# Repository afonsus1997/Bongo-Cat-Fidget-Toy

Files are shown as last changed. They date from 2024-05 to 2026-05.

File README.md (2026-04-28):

# Bongo Cat Fidget Toy

<p align="center">
  Demo 1
  Demo 2
</p>







A simple and satisfying electronic fidget toy featuring Bongo Cat. Track your taps, measure your speed, and toggle display options with intuitive controls.

> 

> **Now available on [Tindie](https://www.tindie.com/products/afonsus1997/bongo-cat-fidget-toy/)!**

---

## Features

* Tap counter with automatic saving to persistent memory  
* Tap speed measurement  
* Milestones
* Sleep animation
* Optional overlay display  

---

## Instructions

### Power

- Requires a single CR2032 battery (positive side up)

### In-Use Controls

* **Hold both buttons** to enable or disable the overlay
  
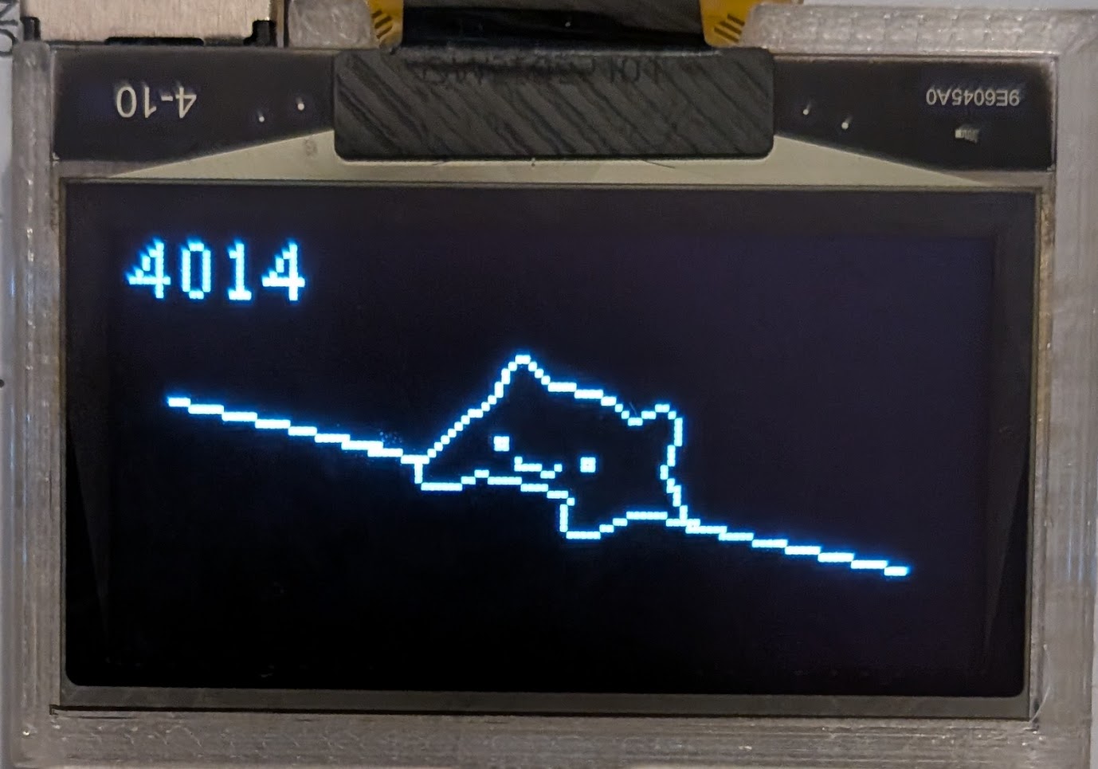
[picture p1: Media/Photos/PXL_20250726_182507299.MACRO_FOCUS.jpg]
  

### Power-On Modes

* **Hold the right button while powering on** to enter reset mode
  
  An additional press is required to confirm
  
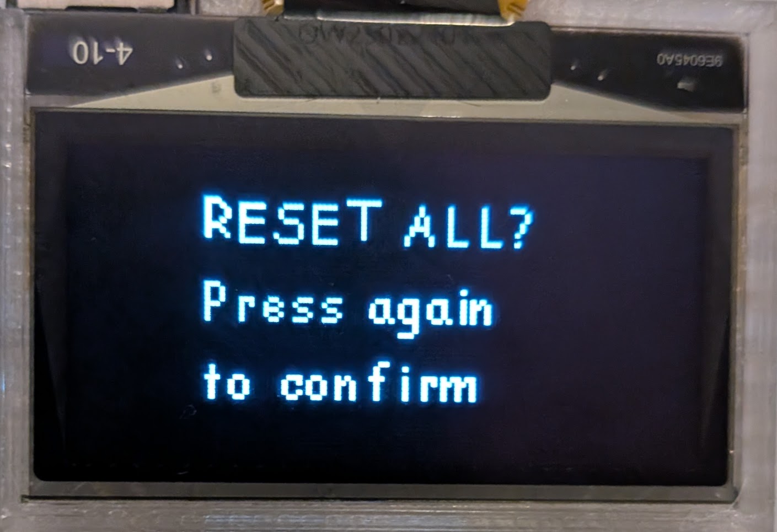
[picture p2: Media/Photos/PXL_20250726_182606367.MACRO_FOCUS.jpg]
  

* **Hold both buttons while powering on** to display the credits
  
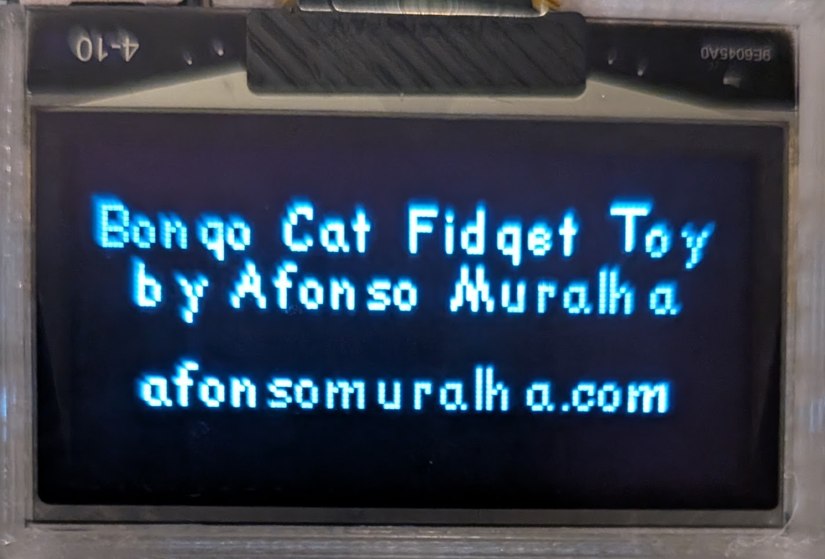
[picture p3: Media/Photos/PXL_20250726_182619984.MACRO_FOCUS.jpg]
  

---

## Gallery

|  |  |
| --- | --- |
|  |  |
|  |  |

---

## Credits

* Switch models by [koktoh](https://github.com/koktoh/keyswitch_model)

---

## AI Disclaimer

All hardware design, firmware, and software in this project were developed by hand. No AI tools were used for circuit design, PCB layout, firmware architecture, code logic, or image/asset generation. AI assistance was limited to aiding software development debugging and porting efforts.

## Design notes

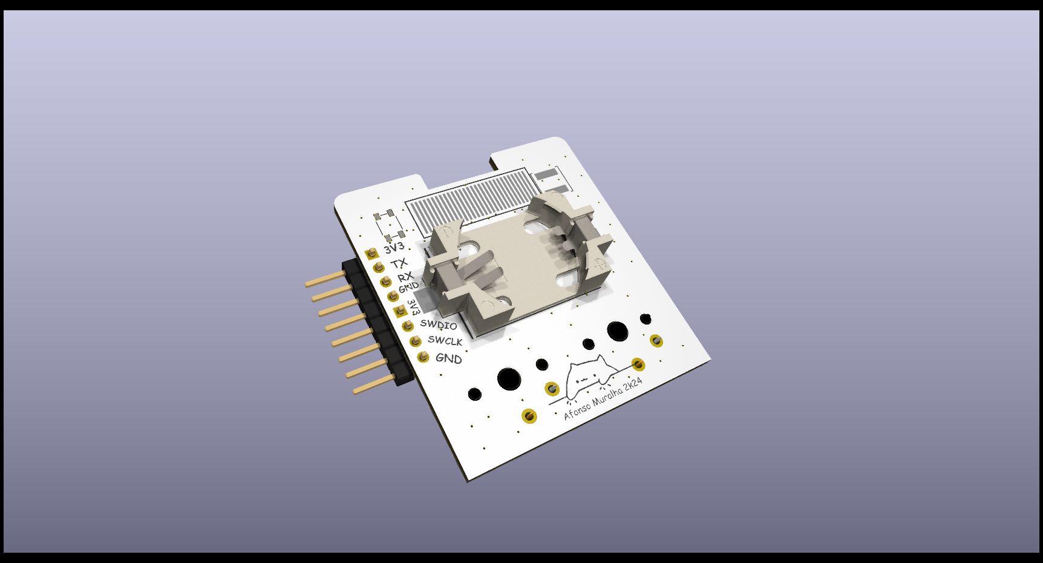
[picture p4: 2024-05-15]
Hardware/Bongo-Cat-Fidget-Toy-Lite/Bongo-Cat-Fidget-Toy-Lite/media/render_bot.png

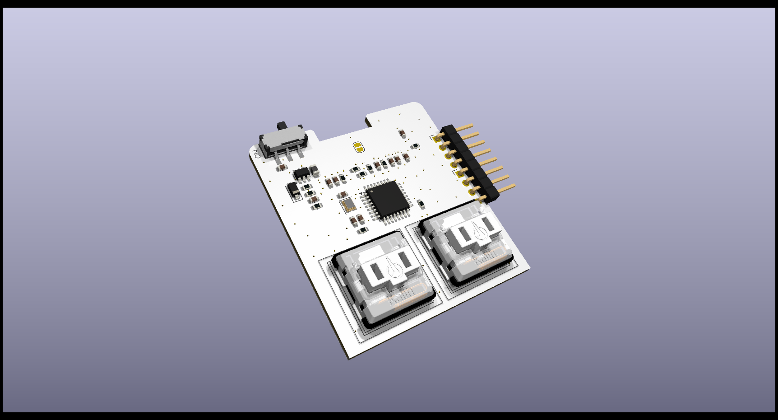
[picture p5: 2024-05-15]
Hardware/Bongo-Cat-Fidget-Toy-Lite/Bongo-Cat-Fidget-Toy-Lite/media/render_top.png

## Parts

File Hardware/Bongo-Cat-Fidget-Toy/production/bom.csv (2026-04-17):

Designator | Footprint | Quantity | Value | LCSC Part #
BT1 | BAT-TH_CR2032-BS-6-1 | 1 | Battery | C70377
C1, C2 | 603 | 2 | 22uF | C59461
C10, C11, C13, C8, C9 | 603 | 5 | 2.2uF | C23630
C12, C4 | 603 | 2 | 4.7uF | C1705
C3, C5 | 603 | 2 | 100nF | C30926
L102 | L_Wurth_WE-LQSH-2010 | 1 | 0.47uH | C89446
R1, R101, R2, R4, R8 | 603 | 5 | 91k | C326721
R11 | 603 | 1 | 390k | C23150
R12, R13 | 603 | 2 | 4.7k | C23162
R6 | 603 | 1 | 511k | C2684557
SW5 | SW-SMD_SK-3245S-L1-A-1 | 1 | SW_SPDT_321 | C405951
U1 | LQFP-32_7x7mm_P0.8mm | 1 | STM32G030K8Tx | C724044
U101 | VREG_TPS63802DLAR | 1 | TPS63802DLAR | C2845237

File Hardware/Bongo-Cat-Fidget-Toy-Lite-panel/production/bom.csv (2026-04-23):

Designator | Footprint | Quantity | Value | LCSC Part #
BT1_12, BT1_11, BT1_10, BT1_9, BT1_8, BT1_7, BT1_6, BT1_5, BT1_4, BT1_3, BT1_2, BT1 | BAT-TH_CR2032-BS-6-1 | 12 | Battery | C70377
C1_12, C1_11, C1_10, C1_9, C1_8, C1_7, C1_6, C1_5, C1_4, C1_3, C1_2, C1, C2_12, C2_11, C2_10, C2_9, C2_8, C2_7, C2_6, C2_5, C2_4, C2_3, C2_2, C2 | 0603 | 24 | 22uF | C59461
C10_12, C10_11, C10_10, C10_9, C10_8, C10_7, C10_6, C10_5, C10_4, C10_3, C10_2, C10, C11_12, C11_11, C11_10, C11_9, C11_8, C11_7, C11_6, C11_5, C11_4, C11_3, C11_2, C11, C13_12, C13_11, C13_10, C13_9, C13_8, C13_7, C13_6, C13_5, C13_4, C13_3, C13_2, C13, C8_12, C8_11, C8_10, C8_9, C8_8, C8_7, C8_6, C8_5, C8_4, C8_3, C8_2, C8, C9_12, C9_11, C9_10, C9_9, C9_8, C9_7, C9_6, C9_5, C9_4, C9_3, C9_2, C9 | 0603 | 60 | 2.2uF
C12_12, C12_11, C12_10, C12_9, C12_8, C12_7, C12_6, C12_5, C12_4, C12_3, C12_2, C12, C4_12, C4_11, C4_10, C4_9, C4_8, C4_7, C4_6, C4_5, C4_4, C4_3, C4_2, C4 | 0603 | 24 | 4.7uF | C1705
C3_12, C3_11, C3_10, C3_9, C3_8, C3_7, C3_6, C3_5, C3_4, C3_3, C3_2, C3 | 0603 | 12 | 100nF
L102_12, L102_11, L102_10, L102_9, L102_8, L102_7, L102_6, L102_5, L102_4, L102_3, L102_2, L102 | L_Wurth_WE-LQSH-2010 | 12 | 0.47uH | C89446
R101_12, R101_11, R101_10, R101_9, R101_8, R101_7, R101_6, R101_5, R101_4, R101_3, R101_2, R101, R4_12, R4_11, R4_10, R4_9, R4_8, R4_7, R4_6, R4_5, R4_4, R4_3, R4_2, R4 | 0603 | 24 | 91k
R11_12, R11_11, R11_10, R11_9, R11_8, R11_7, R11_6, R11_5, R11_4, R11_3, R11_2, R11 | 0603 | 12 | 390k
R12_12, R12_11, R12_10, R12_9, R12_8, R12_7, R12_6, R12_5, R12_4, R12_3, R12_2, R12, R13_12, R13_11, R13_10, R13_9, R13_8, R13_7, R13_6, R13_5, R13_4, R13_3, R13_2, R13 | 0603 | 24 | 4.7k
R6_12, R6_11, R6_10, R6_9, R6_8, R6_7, R6_6, R6_5, R6_4, R6_3, R6_2, R6 | 0603 | 12 | 511k
SW5_12, SW5_11, SW5_10, SW5_9, SW5_8, SW5_7, SW5_6, SW5_5, SW5_4, SW5_3, SW5_2, SW5 | SW-SMD_SK-3245S-L1-A-1 | 12 | SW_SPDT_321 | C405951
U101_12, U101_11, U101_10, U101_9, U101_8, U101_7, U101_6, U101_5, U101_4, U101_3, U101_2, U101 | VREG_TPS63802DLAR | 12 | TPS63802DLAR | C2845237
U2_12, U2_11, U2_10, U2_9, U2_8, U2_7, U2_6, U2_5, U2_4, U2_3, U2_2, U2 | QFN-20-1EP_3x3mm_P0.4mm_EP1.65x1.65mm | 12 | PY32F003F1xU | C3018714

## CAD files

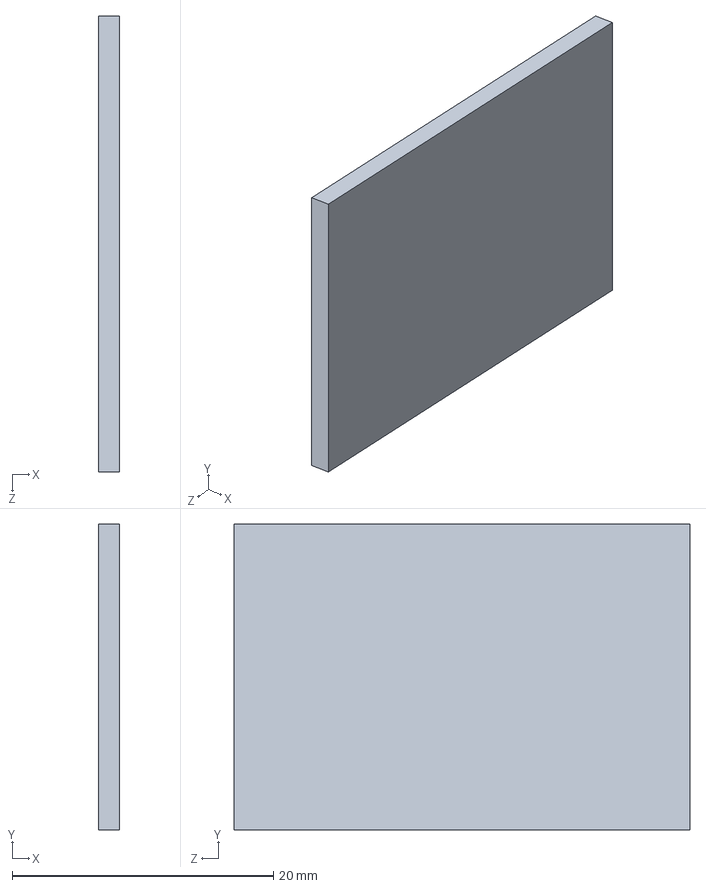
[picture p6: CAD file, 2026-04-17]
Hardware/3D/LCD.SLDPRT
1.60 x 23.4 x 34.9 mm

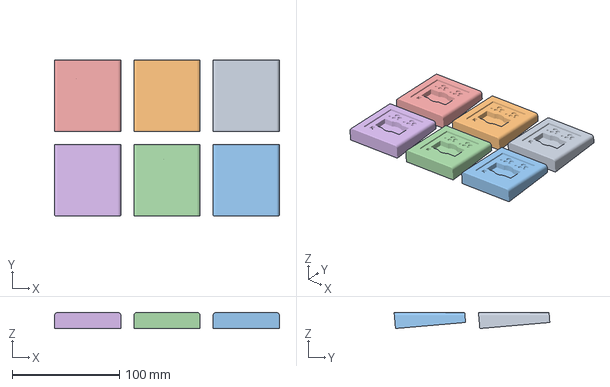
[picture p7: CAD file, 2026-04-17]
Hardware/Bongo-Cat-Fidget-Toy-Lite/Bongo-Cat-Fidget-Toy-Lite/box_insert_bambulab.3mf
210.0 x 145.4 x 15.0 mm
box_insert.stl x 6

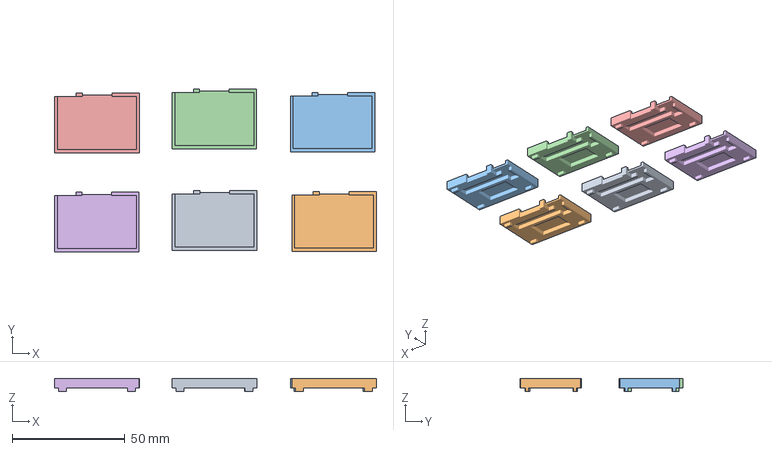
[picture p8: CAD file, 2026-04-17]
Hardware/Bongo-Cat-Fidget-Toy/LCD_support_bambulab_new.3mf
142.5 x 72.2 x 5.95 mm
LCD Support - LCD Support-1.STL x 6

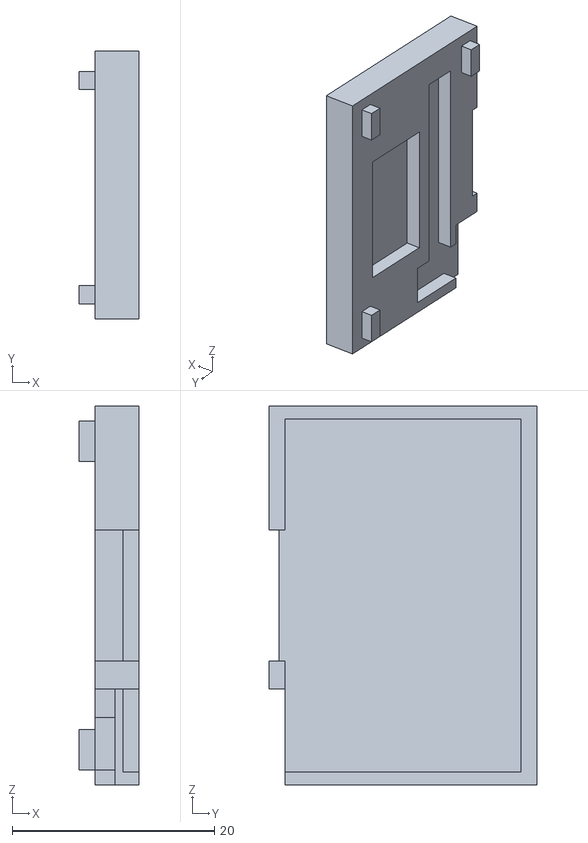
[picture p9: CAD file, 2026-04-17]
Hardware/3D/LCD Support_0.0.STL
5.95 x 26.5 x 37.5

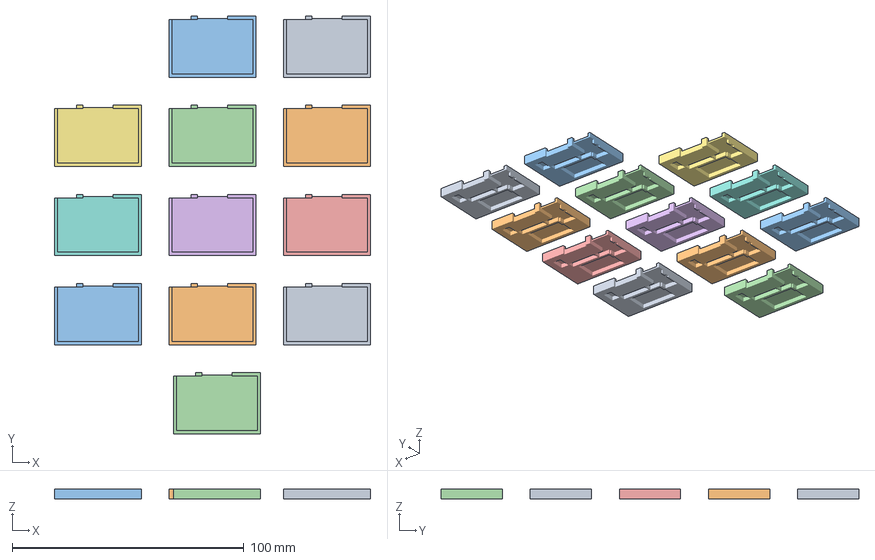
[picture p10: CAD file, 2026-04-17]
Hardware/Bongo-Cat-Fidget-Toy-Lite/Bongo-Cat-Fidget-Toy-Lite/LCD_support_bambulab.3mf
136.5 x 180.5 x 4.35 mm
LCD support.stl x 12

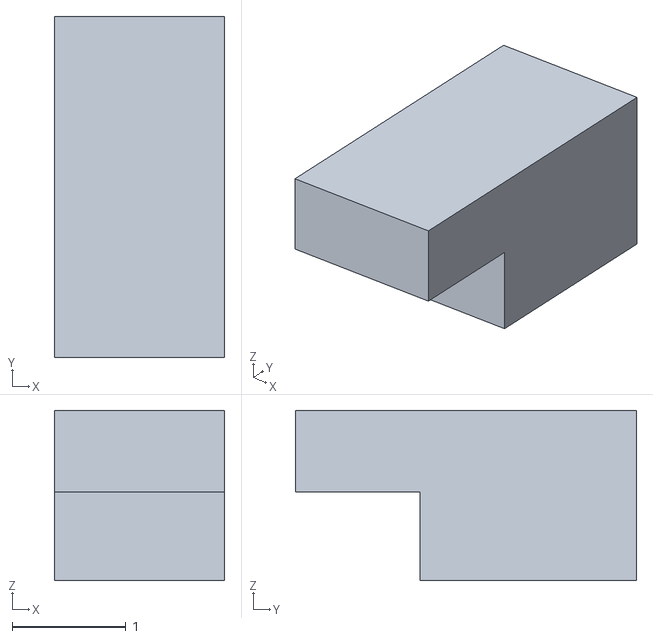
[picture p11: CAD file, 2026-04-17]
Hardware/3D/LCD Support - Bongo-Cat-Fidget-Toy.step-1 SW-SMD_SK-3245S-L1-A-1.step-1 SOLID-1.step-1.STL
1.50 x 3.00 x 1.50

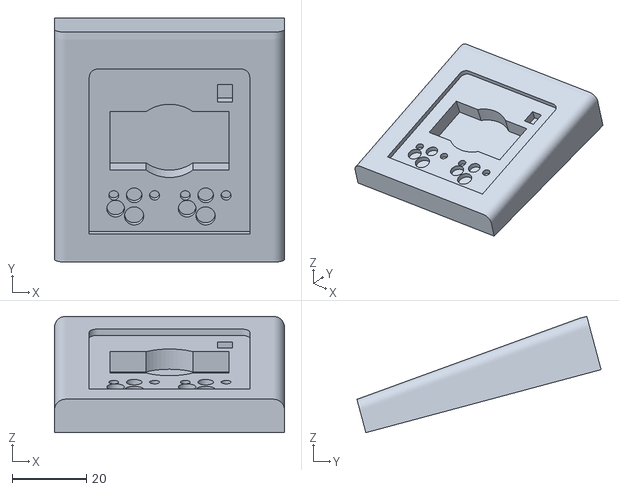
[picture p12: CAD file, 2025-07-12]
Hardware/Bongo-Cat-Fidget-Toy-Lite/Bongo-Cat-Fidget-Toy-Lite/box_insert.stl
62.0 x 65.8 x 31.4

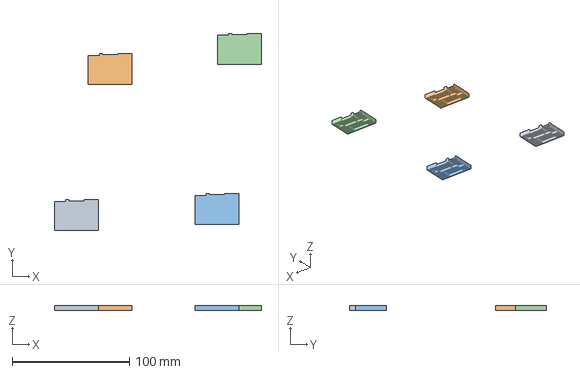
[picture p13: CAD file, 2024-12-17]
Hardware/Bongo-Cat-Fidget-Toy/LCD_support_bambulab.3mf
176.7 x 168.4 x 4.35 mm
LCD support.stl x 4

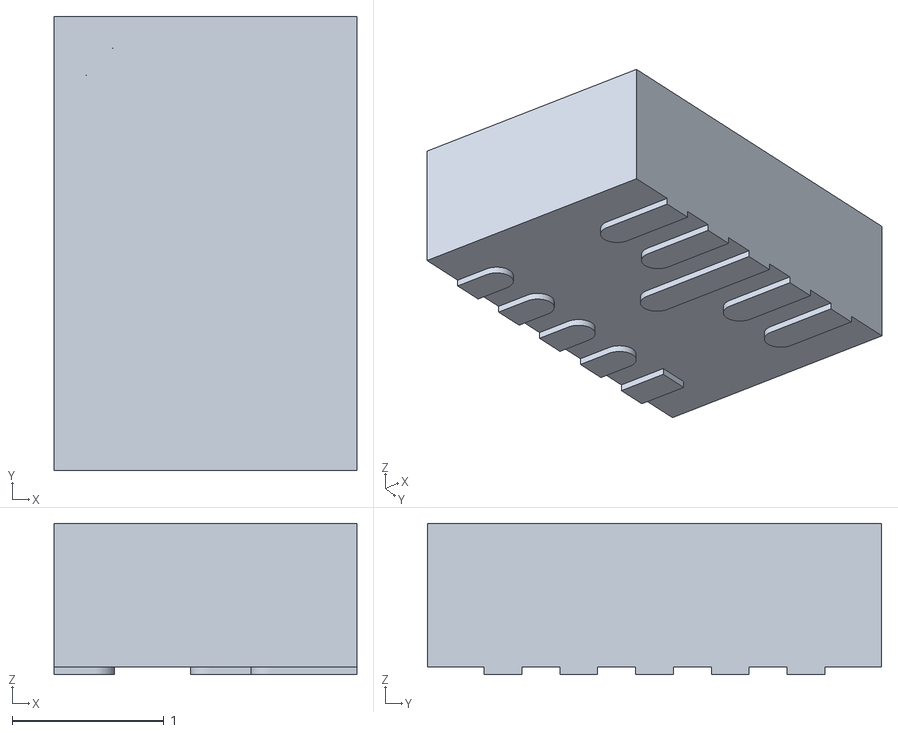
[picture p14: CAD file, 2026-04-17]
Hardware/3D/LCD Support - Bongo-Cat-Fidget-Toy.step-1 TPS63802DLAR.step-1.STL
2.00 x 3.00 x 1.00

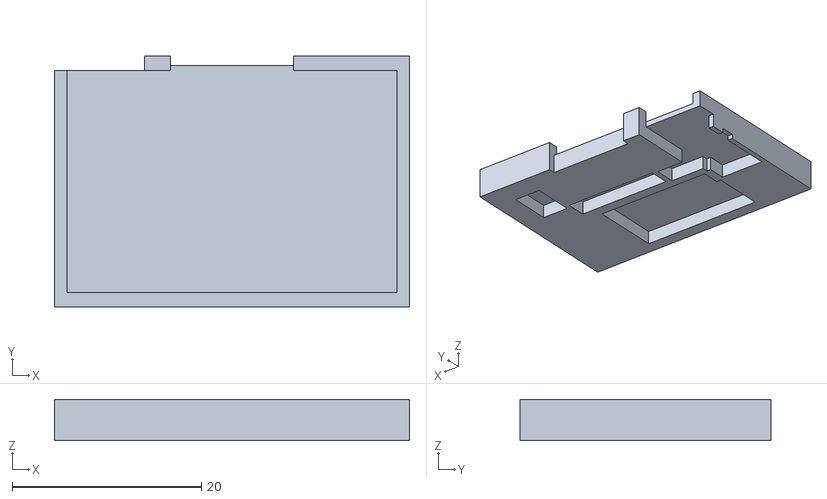
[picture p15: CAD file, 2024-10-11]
Hardware/Bongo-Cat-Fidget-Toy-Lite/Bongo-Cat-Fidget-Toy-Lite/LCD support.stl
37.5 x 26.5 x 4.35

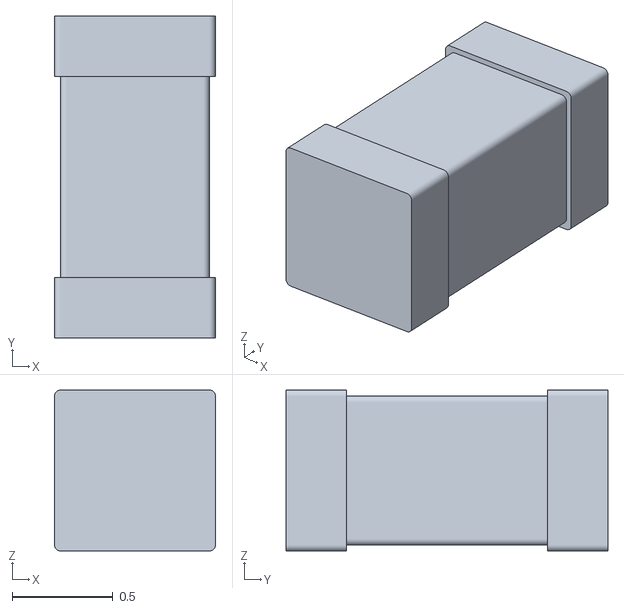
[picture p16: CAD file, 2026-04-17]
Hardware/3D/LCD Support - Bongo-Cat-Fidget-Toy.step-1 C_0603_1608Metric.step-11.STL
0.8 x 1.60 x 0.8

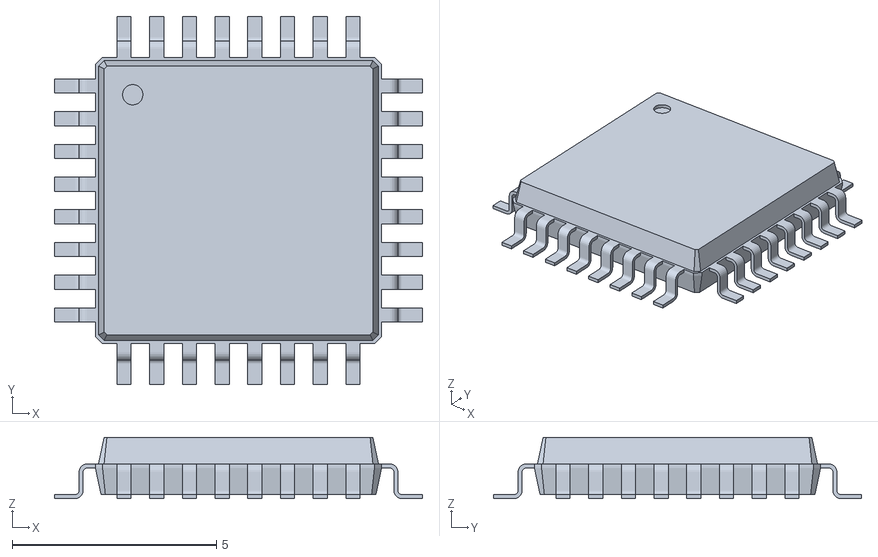
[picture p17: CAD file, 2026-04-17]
Hardware/3D/LCD Support - Bongo-Cat-Fidget-Toy.step-1 LQFP-32_7x7mm_P0.8mm.step-1.STL
9.00 x 9.00 x 1.50

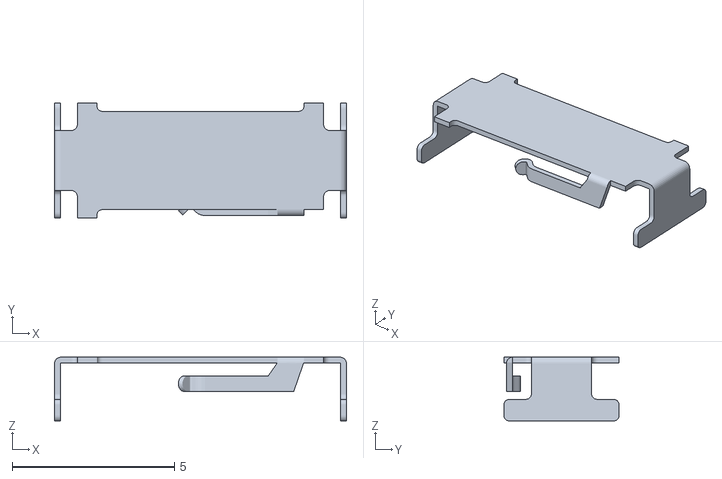
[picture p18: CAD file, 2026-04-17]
Hardware/3D/LCD Support - Bongo-Cat-Fidget-Toy.step-1 SW-SMD_SK-3245S-L1-A-1.step-1 SOLID-0.step-1.STL
9.00 x 3.55 x 1.97

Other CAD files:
Hardware/Bongo-Cat-Fidget-Toy/box_insert_bambulab.3mf
Hardware/3D/LCD Support - Bongo-Cat-Fidget-Toy.step-1 C_0603_1608Metric.step-2.STL
Hardware/3D/LCD Support - Bongo-Cat-Fidget-Toy.step-1 C_0603_1608Metric.step-5.STL
Hardware/3D/LCD Support_-0.2.STL
Hardware/3D/LCD Support_-0.1.STL
Hardware/3D/LCD Support - Bongo-Cat-Fidget-Toy.step-1 Bongo-Cat-Fidget-Toy_PCB.step-1.STL
Hardware/3D/LCD Support - Bongo-Cat-Fidget-Toy.step-1 C_0603_1608Metric.step-1.STL
Hardware/3D/LCD Support - Bongo-Cat-Fidget-Toy.step-1 C_0603_1608Metric.step-10.STL
Hardware/3D/LCD Support - Bongo-Cat-Fidget-Toy.step-1 C_0603_1608Metric.step-3.STL
Hardware/3D/LCD Support - Bongo-Cat-Fidget-Toy.step-1 C_0603_1608Metric.step-4.STL
Hardware/3D/LCD Support - Bongo-Cat-Fidget-Toy.step-1 C_0603_1608Metric.step-6.STL
Hardware/3D/LCD Support - Bongo-Cat-Fidget-Toy.step-1 C_0603_1608Metric.step-7.STL
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

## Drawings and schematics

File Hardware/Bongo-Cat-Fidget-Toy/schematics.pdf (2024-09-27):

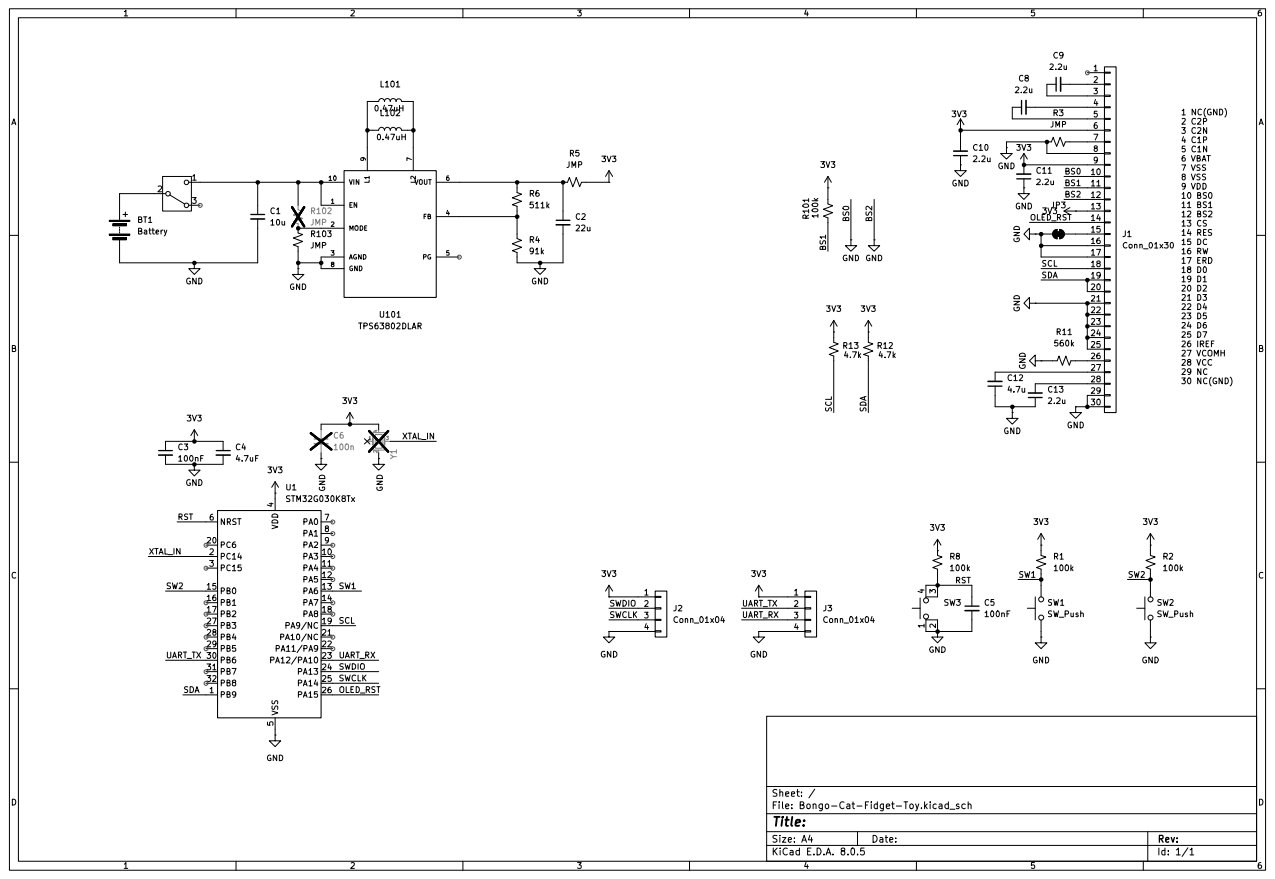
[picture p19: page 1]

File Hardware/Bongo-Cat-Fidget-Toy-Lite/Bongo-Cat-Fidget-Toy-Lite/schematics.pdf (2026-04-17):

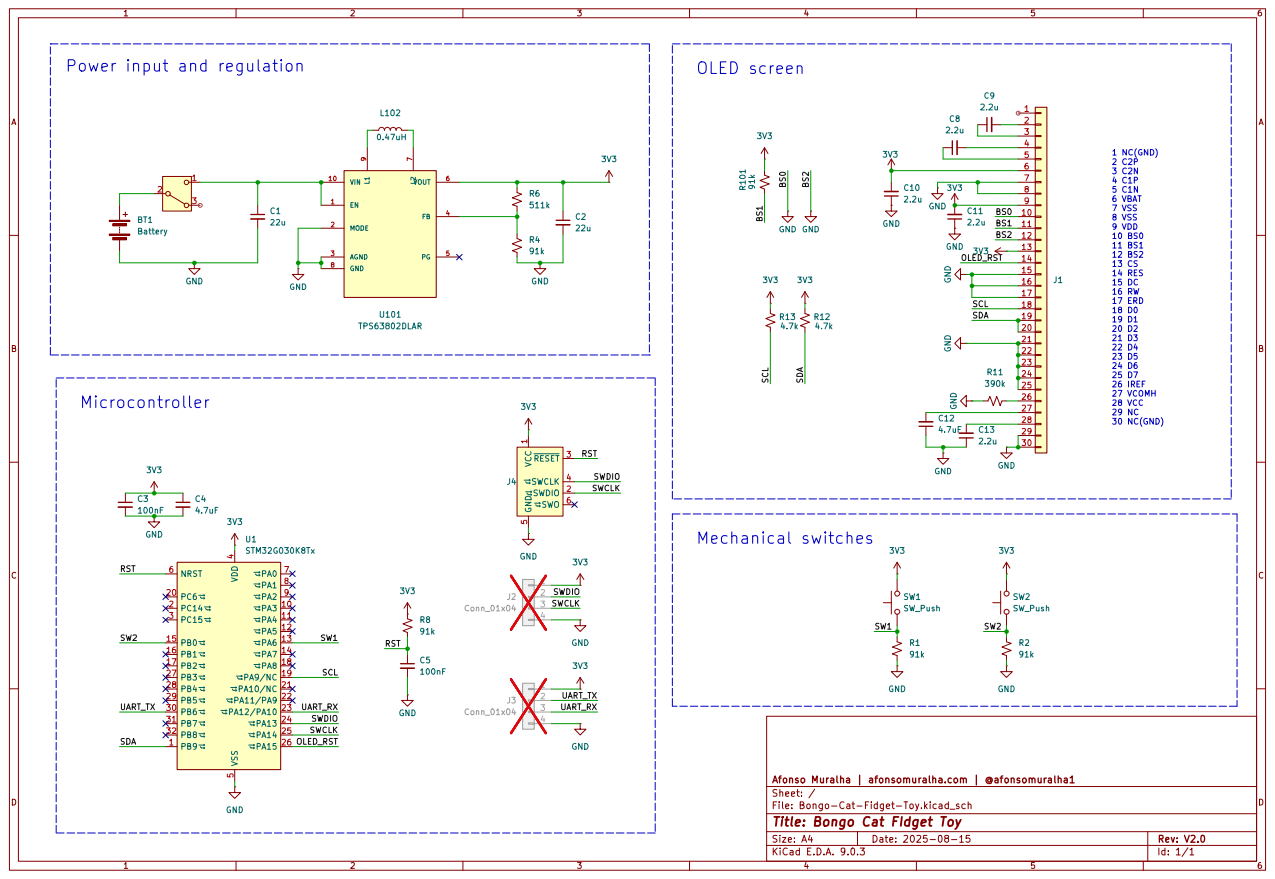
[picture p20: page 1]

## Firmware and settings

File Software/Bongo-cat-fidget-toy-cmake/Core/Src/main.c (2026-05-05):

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
/* Includes ------------------------------------------------------------------*/
#include "main.h"

/* USER CODE BEGIN Includes */
#include "ssd1306.h"
#include "buttons.h"
#include "settings.h"
#include "tap_tracker.h"
#include "animation.h"
#include "ui.h"
/* USER CODE END Includes */

/* USER CODE BEGIN PTD */
typedef enum {
    IDLE,
    SWITCH,
} state_e;
/* USER CODE END PTD */

I2C_HandleTypeDef hi2c1;
TIM_HandleTypeDef htim14;

void SystemClock_Config(void);
static void MX_GPIO_Init(void);
static void MX_I2C1_Init(void);
static void MX_TIM14_Init(void);
static void MX_NVIC_Init(void);
/* USER CODE BEGIN 0 */
void HAL_TIM_PeriodElapsedCallback(TIM_HandleTypeDef *htim)
{
    if (htim == &htim14)
    {
        readPins();
    }
}
/* USER CODE END 0 */

/**
  * @brief  The application entry point.
  * @retval int
  */
int main(void)
{
  HAL_Init();

  SystemClock_Config();

  MX_GPIO_Init();
  MX_I2C1_Init();
  MX_TIM14_Init();
  MX_NVIC_Init();

  /* USER CODE BEGIN 2 */
  HAL_GPIO_WritePin(OLED_RST_GPIO_Port, OLED_RST_Pin, GPIO_PIN_RESET);
  HAL_Delay(10);
  HAL_GPIO_WritePin(OLED_RST_GPIO_Port, OLED_RST_Pin, GPIO_PIN_SET);
  ssd1306_Init();
  ssd1306_SetContrast(DISPLAY_CONTRAST);

  tap_tracker_reset();
  last_save_time = HAL_GetTick();

  handle_boot_overrides();
  load_settings();

  state_e state       = IDLE;
  uint8_t idle_cnt    = 0;
  int32_t idle_cntr   = 0;
  int32_t tap_left_cntr  = 0;
  int32_t tap_right_cntr = 0;
  uint8_t left_state  = 0;
  uint8_t right_state = 0;

  uint32_t idle_since      = 0;
  uint32_t sleep_zzz_timer = 0;
  uint8_t  sleep_zzz_frame = 0;

  HAL_TIM_Base_Start_IT(&htim14);

  while (1) {
    check_and_save();
    update_saved_indicator();
    update_tap_speed();

    switch (state) {
    case IDLE:
        if (sw_state_left == 0 || sw_state_right == 0) {
            if (!ssd1306_GetDisplayOn()) ssd1306_SetDisplayOn(1);
            state        = SWITCH;
            idle_since   = 0;
        } else {
            if (idle_since == 0) {
                idle_since      = HAL_GetTick();
                sleep_zzz_timer = idle_since;
                sleep_zzz_frame = 0;
            }

            uint32_t elapsed = HAL_GetTick() - idle_since;

            if (elapsed >= SLEEP_DELAY + DISPLAY_OFF_DELAY) {
                if (ssd1306_GetDisplayOn()) ssd1306_SetDisplayOn(0);
            } else if (elapsed >= SLEEP_DELAY) {
                draw_sleep_frame();
                draw_zzz_overlay(sleep_zzz_frame);
                update_display_with_overlays();
                if (HAL_GetTick() - sleep_zzz_timer >= SLEEP_ZZZ_PERIOD) {
                    sleep_zzz_frame = (sleep_zzz_frame + 1) % 4;
                    sleep_zzz_timer = HAL_GetTick();
                }
            } else {
                draw_idle_frame(idle_cnt);
                update_display_with_overlays();
                idle_cnt = (idle_cnt + 1) % idle_frame_count();
            }

            uint32_t t = HAL_GetTick();
            while (HAL_GetTick() - t < 100) __WFI();
        }
        break;

    case SWITCH:
        handle_display_mode_switch();

        if (check_idle_transition(&idle_cntr, &left_state, &right_state)) {
            state      = IDLE;
            idle_since = 0;
        } else if (!NONE_PRESSED) {
            handle_paw_animations(&left_state, &right_state,
                                  &tap_left_cntr, &tap_right_cntr, &idle_cntr);
        }

        if (pending_milestone) {
            HAL_TIM_Base_Stop_IT(&htim14);
            play_milestone_celebration(pending_milestone);
            pending_milestone = 0;
            HAL_TIM_Base_Start_IT(&htim14);
            readPins();
            while (!NONE_PRESSED) { readPins(); HAL_Delay(10); }
            left_state     = 0;
            right_state    = 0;
            tap_left_cntr  = 0;
            tap_right_cntr = 0;
            idle_cntr      = 0;
            tap_tracker_reset();
            save_settings();
        }

        handle_tap_decay(&tap_left_cntr, &tap_right_cntr);
        update_display_with_overlays();
        break;
    }
  }
  /* USER CODE END 2 */

  /* Infinite loop */
  /* USER CODE BEGIN WHILE */
  while (1)
  {
    /* USER CODE END WHILE */

    /* USER CODE BEGIN 3 */
  }
  /* USER CODE END 3 */
}

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


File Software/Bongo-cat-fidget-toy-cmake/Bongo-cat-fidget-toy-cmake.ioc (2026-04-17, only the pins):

Mcu.UserName=STM32G030K8Tx
PA13.Signal=SYS_SWDIO
PA14-BOOT0.Signal=SYS_SWCLK
PA15.GPIO_Label=OLED_RST
PA15.Signal=GPIO_Output
PA6.GPIO_Label=SW_LEFT
PA6.Signal=GPIO_Input
PA9.Signal=I2C1_SCL
PB0.GPIO_Label=SW_RIGHT
PB0.Signal=GPIO_Input
PB9.Signal=I2C1_SDA

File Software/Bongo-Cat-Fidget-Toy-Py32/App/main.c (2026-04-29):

/**
  ******************************************************************************
  * @file    main.c
  * @author  MCU Application Team
  * @brief   Main program body
  ******************************************************************************
  * @attention
  *
  * <h2><center>&copy; Copyright (c) Puya Semiconductor Co.
  * All rights reserved.</center></h2>
  *
  * <h2><center>&copy; Copyright (c) 2016 STMicroelectronics.
  * All rights reserved.</center></h2>
  *
  * This software component is licensed by ST under BSD 3-Clause license,
  * the "License"; You may not use this file except in compliance with the
  * License. You may obtain a copy of the License at:
  *                        opensource.org/licenses/BSD-3-Clause
  *
  ******************************************************************************
  */
/* Includes ------------------------------------------------------------------*/
#include "main.h"
#include "py32f003x6.h"
#include "py32f0xx_hal_gpio.h"
#include "ssd1306.h"
#include "ssd1306_conf.h"
#include "bongo.h"


I2C_HandleTypeDef I2cHandle;

#define I2C_ADDRESS      0xA0
#define I2C_SPEEDCLOCK   400000          /* 400kHz fast mode to match STM32 */
#define I2C_DUTYCYCLE    I2C_DUTYCYCLE_16_9

#define OLED_RST_GPIO_Port GPIOA
#define OLED_RST_Pin GPIO_PIN_12

static void APP_I2cConfig(void);
static void APP_GpioConfig(void);

void run_bongo_loop(void)
{
    state_e state = IDLE;
    uint8_t idle_cnt       = 0;
    uint8_t left_state     = 0;
    uint8_t right_state    = 0;
    int32_t tap_left_cntr  = 0;
    int32_t tap_right_cntr = 0;
    int32_t idle_cntr      = 0;

    uint32_t idle_since      = 0;
    uint32_t sleep_zzz_timer = 0;
    uint8_t  sleep_zzz_frame = 0;

    while (1)
    {
        readPins();
        check_and_save();
        update_saved_indicator();
        update_tap_speed();

        switch (state) {
        case IDLE:
            if (!NONE_PRESSED) {
                if (!ssd1306_GetDisplayOn()) ssd1306_SetDisplayOn(1);
                state      = SWITCH;
                idle_since = 0;
            } else {
                if (idle_since == 0) {
                    idle_since      = HAL_GetTick();
                    sleep_zzz_timer = idle_since;
                    sleep_zzz_frame = 0;
                }

                uint32_t elapsed = HAL_GetTick() - idle_since;

                if (elapsed >= SLEEP_DELAY + DISPLAY_OFF_DELAY) {
                    if (ssd1306_GetDisplayOn()) ssd1306_SetDisplayOn(0);
                } else if (elapsed >= SLEEP_DELAY) {
                    draw_sleep_frame();
                    draw_zzz_overlay(sleep_zzz_frame);
                    update_display_with_overlays();
                    if (HAL_GetTick() - sleep_zzz_timer >= SLEEP_ZZZ_PERIOD) {
                        sleep_zzz_frame = (sleep_zzz_frame + 1) % 4;
                        sleep_zzz_timer = HAL_GetTick();
                    }
                } else {
                    draw_idle_frame(idle_cnt);
                    update_display_with_overlays();
                    idle_cnt = (idle_cnt + 1) % idle_frame_count();
                }

                uint32_t t = HAL_GetTick();
                while (HAL_GetTick() - t < 100) __WFI();
            }
            break;

        case SWITCH:
            // handle_display_mode_switch();

            if (check_idle_transition(&idle_cntr, &left_state, &right_state)) {
                state      = IDLE;
                idle_since = 0;
            } else if (!NONE_PRESSED) {
                handle_paw_animations(
                    &left_state, &right_state,
                    &tap_left_cntr, &tap_right_cntr,
                    &idle_cntr
                );
            }

            if (pending_milestone) {
                play_milestone_celebration(pending_milestone);
                pending_milestone = 0;
                readPins();
                while (!NONE_PRESSED) { readPins(); HAL_Delay(10); }
                left_state     = 0;
                right_state    = 0;
                tap_left_cntr  = 0;
                tap_right_cntr = 0;
                idle_cntr      = 0;
                tap_tracker_reset();
                save_settings();
            }

            handle_tap_decay(&tap_left_cntr, &tap_right_cntr);
            update_display_with_overlays();
            break;
        }
    }
}
  
int main(void)
{
  HAL_Init();
  APP_GpioConfig();
  APP_I2cConfig();

  HAL_GPIO_WritePin(OLED_RST_GPIO_Port, OLED_RST_Pin, GPIO_PIN_RESET);
  HAL_Delay(10);
  HAL_GPIO_WritePin(OLED_RST_GPIO_Port, OLED_RST_Pin, GPIO_PIN_SET);
  HAL_Delay(10);
  ssd1306_Init();
  ssd1306_SetContrast(DISPLAY_CONTRAST);

  load_settings();
//   ssd1306_InvertDisplay(settings.display_inverted);
  last_save_time = HAL_GetTick();
  tap_tracker_reset();

  handle_boot_overrides();

  run_bongo_loop();
}

static void APP_GpioConfig(void)
{
  GPIO_InitTypeDef  GPIO_InitStruct;

  __HAL_RCC_GPIOA_CLK_ENABLE();

  /* OLED reset */
  GPIO_InitStruct.Pin   = OLED_RST_Pin;
  GPIO_InitStruct.Mode  = GPIO_MODE_OUTPUT_PP;
  GPIO_InitStruct.Pull  = GPIO_NOPULL;
  GPIO_InitStruct.Speed = GPIO_SPEED_FREQ_LOW;
  HAL_GPIO_Init(OLED_RST_GPIO_Port, &GPIO_InitStruct);

  /* SW_LEFT: PA0, active-high with internal pull-down */
  GPIO_InitStruct.Pin   = SW_LEFT_Pin;
  GPIO_InitStruct.Mode  = GPIO_MODE_INPUT;
  GPIO_InitStruct.Pull  = GPIO_PULLDOWN;
  HAL_GPIO_Init(SW_LEFT_GPIO_Port, &GPIO_InitStruct);

  /* SW_RIGHT: PA1, active-high with internal pull-down */
  GPIO_InitStruct.Pin   = SW_RIGHT_Pin;
  GPIO_InitStruct.Mode  = GPIO_MODE_INPUT;
  GPIO_InitStruct.Pull  = GPIO_PULLDOWN;
  HAL_GPIO_Init(SW_RIGHT_GPIO_Port, &GPIO_InitStruct);
}

static void APP_I2cConfig(void){
  I2cHandle.Instance             = I2C;                                                                   /* I2C */
  I2cHandle.Init.ClockSpeed      = I2C_SPEEDCLOCK;                                                        /* I2C通讯速度 */
  I2cHandle.Init.DutyCycle       = I2C_DUTYCYCLE;                                                         /* I2C占空比 */
  I2cHandle.Init.OwnAddress1     = I2C_ADDRESS;                                                           /* I2C地址 */
  I2cHandle.Init.GeneralCallMode = I2C_GENERALCALL_DISABLE;                                               /* 禁止广播呼叫 */
  I2cHandle.Init.NoStretchMode   = I2C_NOSTRETCH_DISABLE;                                                 /* 允许时钟延长 */
  if (HAL_I2C_Init(&I2cHandle) != HAL_OK)
  {
    APP_ErrorHandler();
  }
}

void APP_ErrorHandler(void)
{
  while (1)
  {
  }
}

#ifdef  USE_FULL_ASSERT
void assert_failed(uint8_t *file, uint32_t line)
{
  while (1)
  {
  }
}
#endif /* USE_FULL_ASSERT */

/************************ (C) COPYRIGHT Puya *****END OF FILE******************/

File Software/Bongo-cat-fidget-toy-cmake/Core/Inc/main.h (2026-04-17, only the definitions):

#define SW_LEFT_Pin GPIO_PIN_6
#define SW_LEFT_GPIO_Port GPIOA
#define SW_RIGHT_Pin GPIO_PIN_0
#define SW_RIGHT_GPIO_Port GPIOB
#define OLED_RST_Pin GPIO_PIN_15
#define OLED_RST_GPIO_Port GPIOA

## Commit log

2024-04-25 Initial design
    [Bongo-Cat-Fidget-Toy.kicad_pcb, Bongo-Cat-Fidget-Toy.kicad_sch]
2024-04-28 Production version
    [Bongo-Cat-Fidget-Toy.kicad_sch, bom.csv, designators.csv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]
2024-05-12 Minor PCB adjustments after production
    [Bongo-Cat-Fidget-Toy.kicad_pcb, Bongo-Cat-Fidget-Toy.kicad_sch]
2024-05-12 updated inductor
    [Bongo-Cat-Fidget-Toy.kicad_sch]
2024-05-15 new revised version sent to production
    [Bongo-Cat-Fidget-Toy.kicad_pcb, Bongo-Cat-Fidget-Toy.kicad_sch, bom.csv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]
2024-05-15 fixed 3d models, minor changes, added ibom
    [Bongo-Cat-Fidget-Toy.kicad_pcb]
2024-06-01 added lcd support
    [LCD support.stl]
2024-09-26 Sw fixes for oled
    [Bongo-Cat-Fidget-Toy.kicad_sch]
2024-09-26 implemented hw fixes
    [Bongo-Cat-Fidget-Toy.kicad_pcb, Bongo-Cat-Fidget-Toy.kicad_sch, bom.csv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]
2024-09-26 new version sent to fab
    [Bongo-Cat-Fidget-Toy.kicad_pcb, Bongo-Cat-Fidget-Toy.kicad_sch, bom.csv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]
2024-09-27 schematic tidy-up, exported pdf
    [Bongo-Cat-Fidget-Toy.kicad_sch]
2024-10-11 updated step and lcd support stl
    [LCD support.stl]
2024-10-20 updated bom
    [Bongo-Cat-Fidget-Toy.kicad_sch, box_insert.stl]
2024-10-20 dni extra inductor
    [Bongo-Cat-Fidget-Toy.kicad_sch]
2024-12-17 added bambulab project
    [LCD_support_bambulab.3mf]
2025-05-28 Bumped to kicad 9.0, Minimal changes, created panel
    [Bongo-Cat-Fidget-Toy-B_Cu.gbr, Bongo-Cat-Fidget-Toy-B_Mask.gbr, Bongo-Cat-Fidget-Toy-B_Paste.gbr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]
2025-05-31 minor layout updates
    [Bongo-Cat-Fidget-Toy.kicad_pcb, Bongo-Cat-Fidget-Toy.kicad_sch, bom.csv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]
2025-05-31 created panel, sent to production
    [Bongo-Cat-Fidget-Toy-B_Cu.gbr, Bongo-Cat-Fidget-Toy-B_Mask.gbr, Bongo-Cat-Fidget-Toy-B_Paste.gbr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]
2025-07-11 updated ibom and added 3mf for box insert
    [box_insert_bambulab.3mf]
2025-07-12 Minor 3d model updates
    [Bongo-Cat-Fidget-Toy-2025 v3.f3z, Bongo-Cat-Fidget-Toy.kicad_pcb, Bongo-Cat-Fidget-Toy.kicad_sch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]
2025-07-19 added box 3mf
    [box_insert_bambulab.3mf]
2025-07-26 Added reset and credits screen
    [main.c]
2025-08-06 Layout and routing updates
    [Bongo-Cat-Fidget-Toy.kicad_pcb, Bongo-Cat-Fidget-Toy.kicad_sch]
2025-08-15 BOM consolidation and mass production adjustments. Schematic tidyup
    [Bongo-Cat-Fidget-Toy.kicad_pcb, Bongo-Cat-Fidget-Toy.kicad_sch]
2025-08-15 Minor adjustments. Exported production files
    [Bongo-Cat-Fidget-Toy.kicad_pcb, Bongo-Cat-Fidget-Toy.kicad_sch, bom.csv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]
2025-08-18 Started working on lite version with py32f003
    [Bongo-Cat-Fidget-Toy-2025 v3.f3z, Bongo-Cat-Fidget-Toy-Lite.kicad_pcb, Bongo-Cat-Fidget-Toy-Lite.kicad_sch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]
2025-12-22 Added tag-connect
    [Bongo-Cat-Fidget-Toy.kicad_pcb, Bongo-Cat-Fidget-Toy.kicad_sch, bom.csv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]
2025-12-22 new panel
    [Bongo-Cat-Fidget-Toy-B_Cu.gbr, Bongo-Cat-Fidget-Toy-B_Mask.gbr, Bongo-Cat-Fidget-Toy-B_Paste.gbr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]
2025-12-22 changed bom switch
    [bom.csv]
2025-12-22 Project problem fix
    [Bongo-Cat-Fidget-Toy.kicad_sch, bom.csv, designators.csv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]
2025-12-22 Exported panel
    [Bongo-Cat-Fidget-Toy.kicad_pcb, bom.csv, designators.csv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]
2025-12-24 Started working on lcd support
    [LCD Support.SLDPRT]
2025-12-24 Lcd support
    [LCD Support - Bongo-Cat-Fidget-Toy.step-1 Bongo-Cat-Fidget-Toy_PCB.step-1.STL, LCD Support - Bongo-Cat-Fidget-Toy.step-1 C_0603_1608Metric.step-1.STL, LCD Supp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]
2025-12-30 Lcd support 3mf
    [LCD_support_bambulab_new.3mf]
2026-01-02 Added keycap model
    [Bongo-Cat-Fidget-Toy.kicad_pcb, LCD.SLDPRT]
2026-04-06 Exported new lcd supports
    [LCD Support.SLDPRT, LCD Support_0.1.STL, LCD Support_0.2.STL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]
2026-04-07 Exported more supports
    [LCD Support_-0.1.STL, LCD Support_-0.2.STL, LCD Support_-0.3.STL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]
2026-04-09 Added more supports
    [LCD Support_0.0.STL]
2026-04-17 Updated panel with fiducials
    [Bongo-Cat-Fidget-Toy.kicad_pcb, Bongo-Cat-Fidget-Toy.kicad_sch, bom.csv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]
2026-04-17 Fixed binary. Exported latest production files
    [bom.csv]
2026-04-23 Ported stm32 code to py32
2026-04-23 Updated code and PCB
    [Bongo-Cat-Fidget-Toy-Lite.kicad_pcb, Bongo-Cat-Fidget-Toy-Lite.kicad_sch]
2026-04-23 Minor change
    [Bongo-Cat-Fidget-Toy-Lite.kicad_sch]
2026-04-23 Lite PCB changes
    [Bongo-Cat-Fidget-Toy-Lite.kicad_pcb, Bongo-Cat-Fidget-Toy-Lite.kicad_sch]
2026-04-23 Lite PCB Panel
    [bom.csv, designators.csv, positions.csv]
2026-04-28 Minor fix. Exported release
    [main.c, tap_tracker.c]
2026-04-28 Fixed bug where both presses caused very high speed
    [main.c, tap_tracker.c]
2026-04-28 Minor fix related to milestones
    [main.c]
2026-04-28 Battery optimizations

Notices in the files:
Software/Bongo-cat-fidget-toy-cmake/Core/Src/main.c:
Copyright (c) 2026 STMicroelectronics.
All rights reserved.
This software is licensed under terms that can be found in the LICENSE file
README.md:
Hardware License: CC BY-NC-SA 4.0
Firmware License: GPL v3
